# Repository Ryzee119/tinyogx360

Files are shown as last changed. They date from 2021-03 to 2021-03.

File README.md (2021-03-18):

# tinyogx360 - Overview

The tinyogx360 is a variation of my [ogx360](https://github.com/Ryzee119/ogx360) project, just a much smaller single player version. It is a circuit board which allows you to use a range of modern USB controllers on the Original Xbox Console. **Note the warnings below prior to building.**

See the main [ogx360 repo](https://github.com/Ryzee119/ogx360) for device firmware. This repo just constains the hardware design files.

This was created using [Autodesk Eagle.](https://www.autodesk.com/products/eagle/overview)

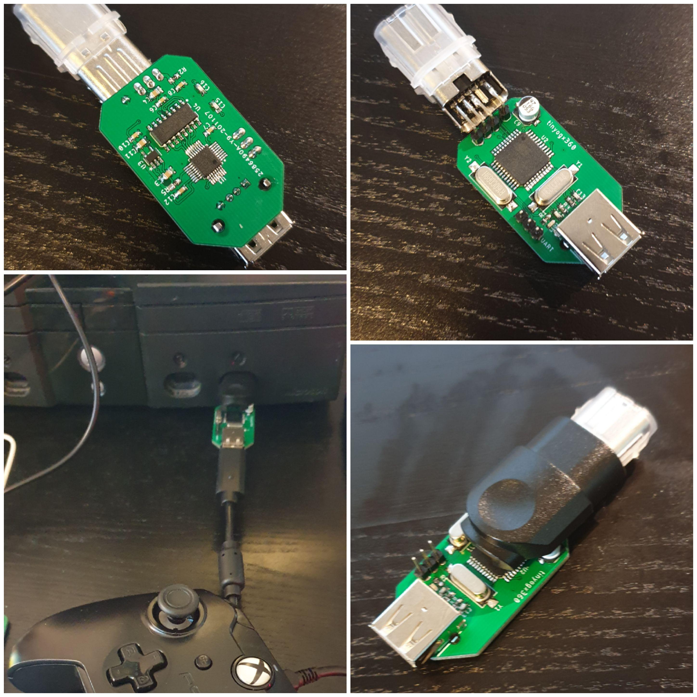
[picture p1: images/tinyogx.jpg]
tinyogx
  

## Ordering
* The PCB Gerbers and BOM are located [here](./.kitspace/).
* These can easily be ordered via [kitspace](https://kitspace.org/boards/github.com/ryzee119/tinyogx360).
* 3D model of the PCB is [here](https://a360.co/2P1Qr6T) (Fusion360).
* You will also need to grab a  [Xbox Controller Port USB adaptor cable](https://www.aliexpress.com/wholesale?catId=0&SearchText=original+xbox+to+usb+adapter) to salvage the connector.

## Schematic
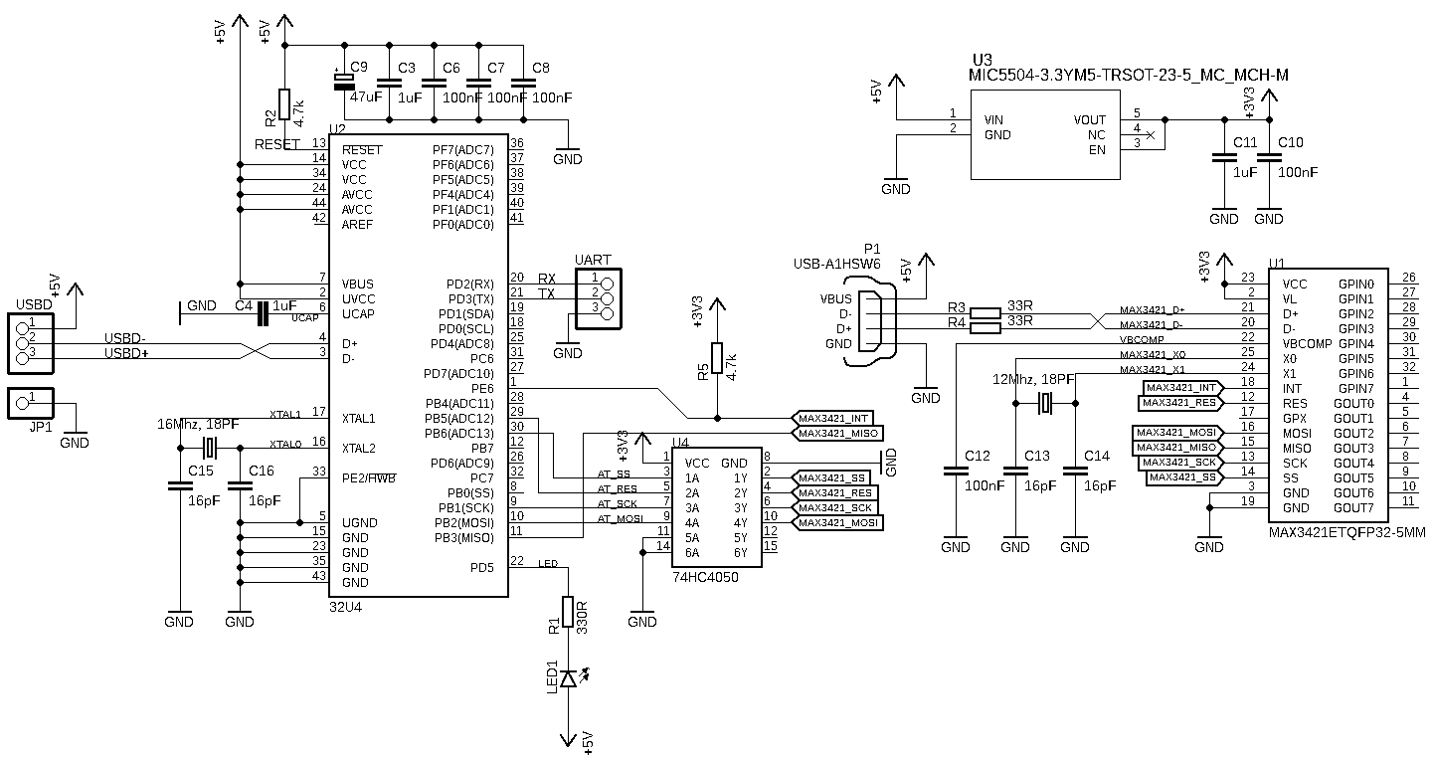
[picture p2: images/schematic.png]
schematic


## WARNING
* Released by request. This is not as tested or as user friendly as the main ogx360 board. You should be comfortable with self-debugging.
* The board does not have any programming headers. The Atmega32u4s should come from factory with a DFU bootloader which can be programmed via the xbox side USB connector.
* I didnt have much luck with this so I hacked on a ISP programming header and programming via TinyISP or any AVR programmer.
* Alternatively program it externally.

By Ryzee119

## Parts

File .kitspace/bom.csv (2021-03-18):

Reference | Qty | Description | Part Number | Manufacturer | Digikey
LED1 | 5 | LED RED 0603 SMD | SML-D12U1WT86 | Rohm Semiconductor | SML-D12U1WT86CT-ND
Y1 | 1 | CRYSTAL 12.0000MHZ 18PF SMD | AS-12.000-18-SMD-TR | Raltron Electronics | 2151-AS-12.000-18-SMD-TRCT-ND
Y2 | 1 | CRYSTAL 16.0000MHZ 18PF SMD | AS-16.000-18-SMD-TR | Raltron Electronics | 2151-AS-16.000-18-SMD-TRCT-ND
U1 | 1 | IC USB PERIPH/HOST CNTRL 32TQFP | MAX3421EEHJ+T | Maxim Integrated | MAX3421EEHJ+TCT-ND
R1 | 10 | RES SMD 330 OHM 5% 1/10W 0603 | CR0603-JW-331ELF | Bourns Inc. | CR0603-JW-331ELFCT-ND
C9 | 5 | CAP ALUM 47UF 20% 16V SMD | EDK476M016A9DAA | KEMET | 399-14791-1-ND
U4 | 1 | IC BUFFER NON-INVERT 6V 16SOIC | 74HC4050D | Toshiba Semiconductor and Storage | 74HC4050DCT-ND
U2 | 1 | IC MCU 8BIT 32KB FLASH 44TQFP | ATMEGA32U4RC-AU | Microchip Technology | ATMEGA32U4RC-AU-ND
U3 | 1 | IC REG LINEAR 3.3V 300MA SOT23-5 | MIC5504-3.3YM5-TR | Microchip Technology | 576-4764-1-ND
P1 | 1 | CONN RCPT TYPEA 4POS R/A | USB-A1HSW6 | On Shore Technology Inc. | ED2989-ND
UART,USBD,JP1 | 5 | CONN HEADER VERT 8POS 2.54MM | 61300811121 | Würth Elektronik | 732-5321-ND
R3,R4 | 10 | RES SMD 33 OHM 1% 1/10W 0603 | CR0603-FX-33R0ELF | Bourns Inc. | 118-CR0603-FX-33R0ELFCT-ND
R2,R5 | 10 | RES SMD 4.7K OHM 5% 1/10W 0603 | CR0603-JW-472ELF | Bourns Inc. | CR0603-JW-472ELFCT-ND
C3,C4,C11 | 10 | CAP CER 1UF 16V X7R 0805 | CL21B105KOFNNNG | Samsung Electro-Mechanics | 1276-6471-1-ND
C13,C14,C15,C16 | 20 | CAP CER 16PF 50V NPO 0603 | CC0603JRNPO9BN160 | Yageo | 311-3964-1-ND
C6,C7,C8,C10,C12 | 20 | CAP CER 0.1UF 50V X7R 0603 | CL10B104KB8NNWC | Samsung Electro-Mechanics | 1276-1935-1-ND

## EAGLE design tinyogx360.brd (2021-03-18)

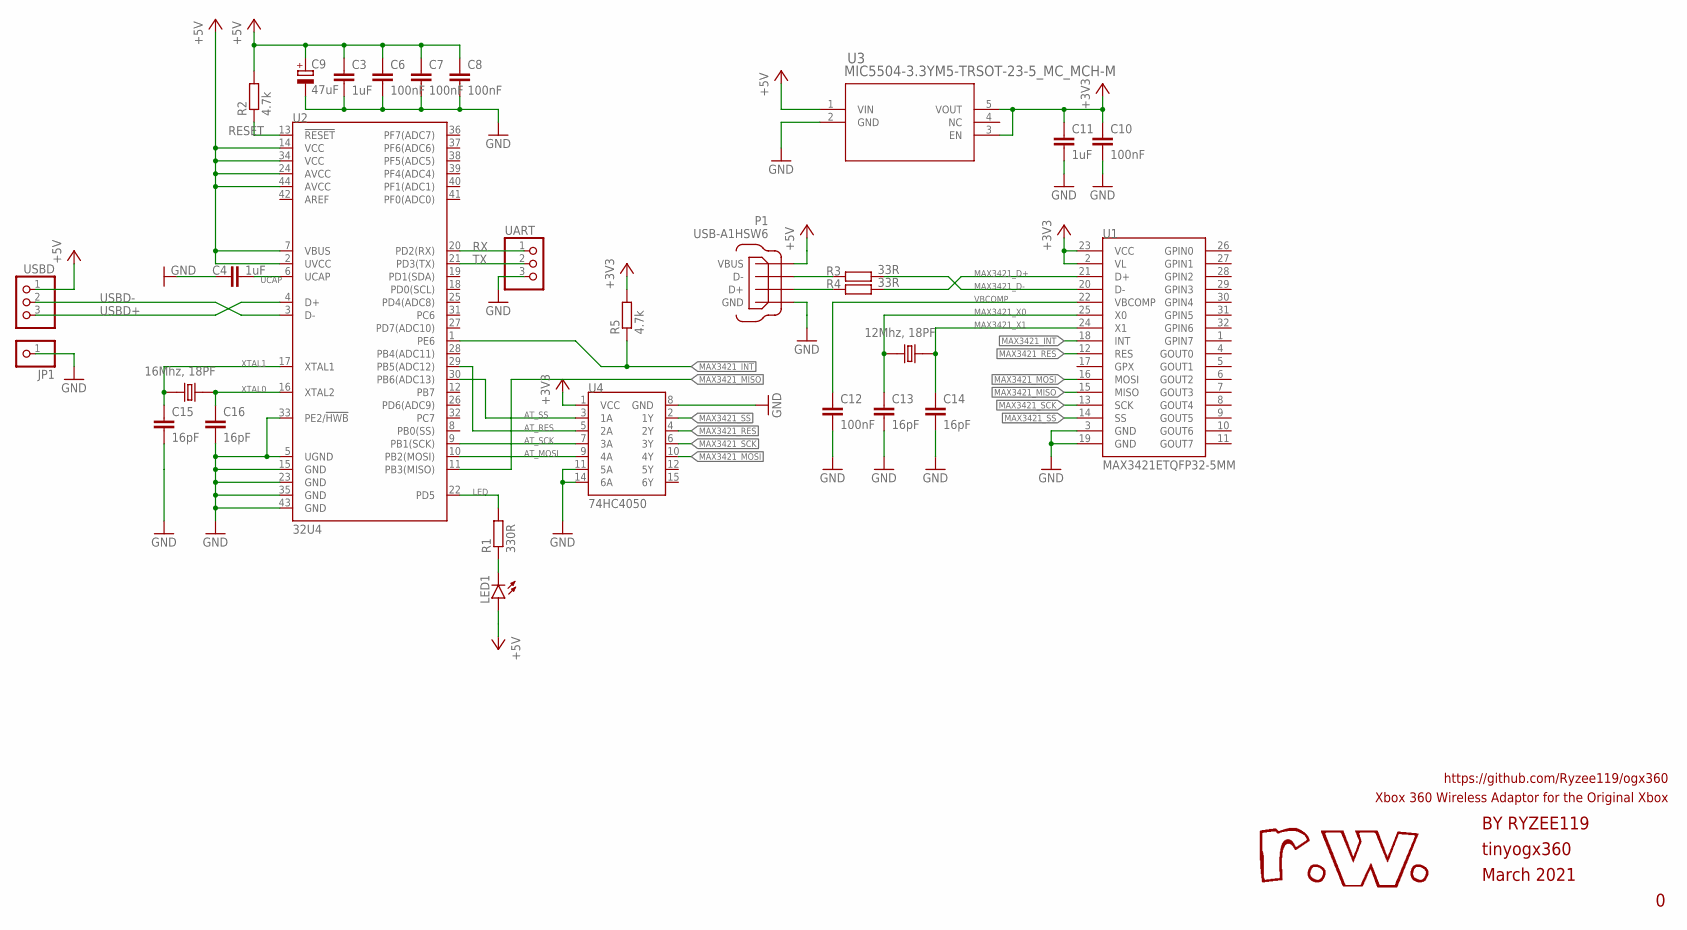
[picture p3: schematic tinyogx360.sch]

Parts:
C3, C4, C11: 1uF; C0805K
C6, C7, C8, C10, C12: 100nF; C0603K
C9: 47uF; 153CLV-0505
C13, C14, C15, C16: 16pF; C0603K
JP1: PINHD-1X1; 1X01
LED1: LEDCHIPLED_0603; CHIPLED_0603
P1: USB-A1HSW6; OST_USB-A1HSW6
R1: 330R; R0603
R2, R5: 4.7k; R0603
R3, R4: 33R; R0603
U1: MAX3421ETQFP32-5MM; TQFP32-5X5MM
U2: 32U4; TQFP44
U3: MIC5504-3.3YM5-TRSOT-23-5_MC_MCH-M; SOT-23-5_MC_MCH-M
U4: 74HC4050; SO16
UART: PINHD-1X3; 1X03
USBD: PINHD-1X3; 1X03
Y1: 12Mhz, 18PF; XTAL_ECS-250-18-5PX-JEM-TR
Y2: 16Mhz, 18PF; XTAL_ECS-250-18-5PX-JEM-TR

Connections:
+3V3: C10.1, C11.1, R5.2, U1.2 (VL), U1.23 (VCC), U3.3 (EN), U3.5 (VOUT), U4.1 (VCC)
+5V: C3.1, C6.1, C7.1, C8.1, C9.+, LED1.A, P1.1 (VBUS), R2.2, U2.2 (UVCC), U2.7 (VBUS), U2.14 (VCC), U2.24 (AVCC), U2.34 (VCC), U2.44 (AVCC), U3.1 (VIN), USBD.1
AT_MOSI: U2.10 (PB2(MOSI)), U4.9 (4A)
AT_RES: U2.29 (PB5(ADC12)), U4.5 (2A)
AT_SCK: U2.9 (PB1(SCK)), U4.7 (3A)
AT_SS: U2.30 (PB6(ADC13)), U4.3 (1A)
GND: C3.2, C4.1, C6.2, C7.2, C8.2, C9.-, C10.2, C11.2, C12.2, C13.2, C14.2, C15.2, C16.2, JP1.1, P1.4 (GND), U1.3 (GND), U1.19 (GND), U2.5 (UGND), U2.15 (GND), U2.23 (GND), U2.33 (PE2/!HWB), U2.35 (GND), U2.43 (GND), U3.2 (GND), U4.8 (GND), U4.11 (5A), U4.14 (6A), UART.3
LED: R1.2, U2.22 (PD5)
MAX3421_D+: R4.2, U1.21 (D+)
MAX3421_D-: R3.2, U1.20 (D-)
MAX3421_INT: R5.1, U1.18 (INT), U2.1 (PE6)
MAX3421_MISO: U1.15 (MISO), U2.11 (PB3(MISO))
MAX3421_MOSI: U1.16 (MOSI), U4.10 (4Y)
MAX3421_RES: U1.12 (RES), U4.4 (2Y)
MAX3421_SCK: U1.13 (SCK), U4.6 (3Y)
MAX3421_SS: U1.14 (SS), U4.2 (1Y)
MAX3421_X0: C13.1, U1.25 (X0), Y1.2
MAX3421_X1: C14.1, U1.24 (X1), Y1.1
unnamed: P1.2 (D-), R3.1
unnamed: P1.3 (D+), R4.1
unnamed: LED1.C, R1.1
RESET: R2.1, U2.13 (!RESET)
RX: U2.20 (PD2(RX)), UART.1
TX: U2.21 (PD3(TX)), UART.2
UCAP: C4.2, U2.6 (UCAP)
USBD+: U2.4 (D+), USBD.3
USBD-: U2.3 (D-), USBD.2
VBCOMP: C12.1, U1.22 (VBCOMP)
XTAL0: C16.1, U2.16 (XTAL2), Y2.1
XTAL1: C15.1, U2.17 (XTAL1), Y2.2

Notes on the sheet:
tinyogx360
March 2021
BY RYZEE119
Xbox 360 Wireless Adaptor for the Original Xbox
https://github.com/Ryzee119/ogx360

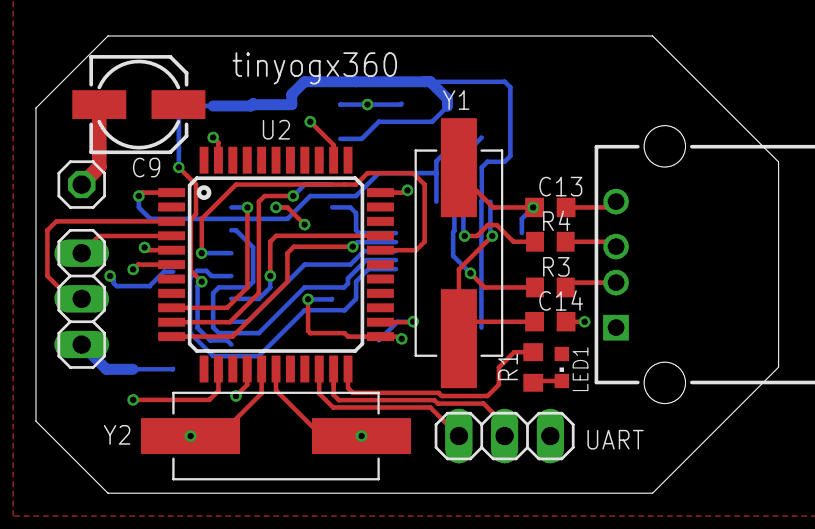
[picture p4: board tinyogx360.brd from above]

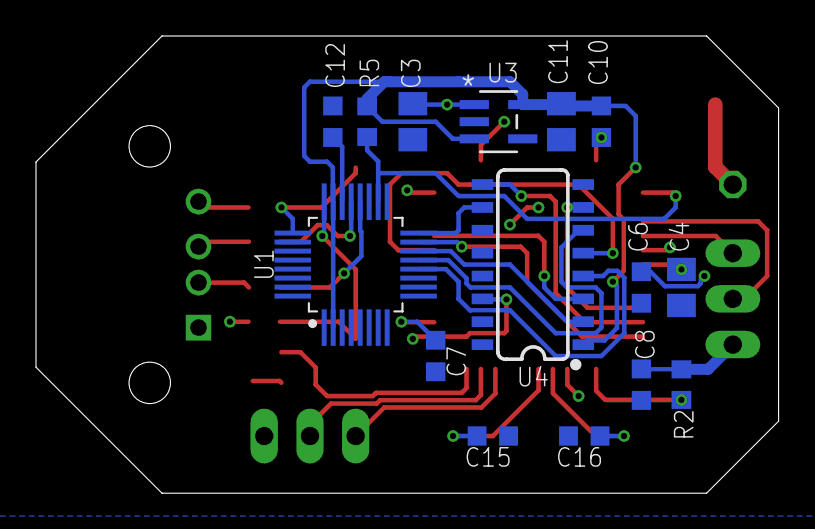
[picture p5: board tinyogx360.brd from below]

Board: 2 copper layers, 41.3 x 25.4 mm, 29 parts (15 on the bottom side), 30 nets.

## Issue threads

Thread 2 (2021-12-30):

how to program

hpx1984, 2021-12-30:
Dear Sir Ryzee119

your project Tinyogx360 seems very interested
i'm really want to try to build it , every thing seems good in the project file (BOM, PCB GERBER, FW)
but just only thing for block me for go ahead the build that is how to program FW
Could you share the way what you know for program the FW
many thanks your project hand hope can get you help for let me join this good project

Ryzee119, 2021-12-30:
See my readme

The board does not have any programming headers. The Atmega32u4s should come from factory with a DFU bootloader which can be programmed via the xbox side USB connector.

I didnt have much luck with this so I hacked on a ISP programming header and programming via TinyISP or any AVR programmer.

Alternatively program it externally

This is for advanced users.

I manually soldered wires to the avr ISP programming points and used my avr programmer

hpx1984, 2021-12-30:
Actual i have got PCB of your original OGX360 project
but seems the Tinyogx360 seems good for me as the BOM is very simple than the original OGX360 project
so i want to try Tinyogx360 first

could you share the photo of your soldered wires and ispProgrammer and program tool
i will try to follow the setup same of your then i think it may easier for success than i just try more other ways

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

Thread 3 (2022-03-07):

3.3V voltage regulator not turning on.

Nurripter, 2022-03-07:
On my boards, the 3.3v regulator enable pin was tied to the Vout of the voltage regulator instead of the Vin of the regulator. This caused the regulator enable to be tied to ground, and stopped the regulator from turning on. To fix this issue, I had to cut the trace heading to the enable pin, and then place a bodge wire to connect the enable pin to Vin.

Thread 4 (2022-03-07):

Firmware not auto detecting board as master

DobaMuffin, 2022-03-07:
Something I noticed when assembling the boards was that the A1 and A2 pins were not properly set, and thus the atmega was going into controller port 4 mode. This meant that it did not communicate with the usb host IC, and controllers were not detected. Currently I've tested two different ways to fix it. The first was to go to an older firmware when there was still a master and slave firmwares, and the second solution was to short the A1 and A2 pins to ground so that the atmega would detect that it is the master.

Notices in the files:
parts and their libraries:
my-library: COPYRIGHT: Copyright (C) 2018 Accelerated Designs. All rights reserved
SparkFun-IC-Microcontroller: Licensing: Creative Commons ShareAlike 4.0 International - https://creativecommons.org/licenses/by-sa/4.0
